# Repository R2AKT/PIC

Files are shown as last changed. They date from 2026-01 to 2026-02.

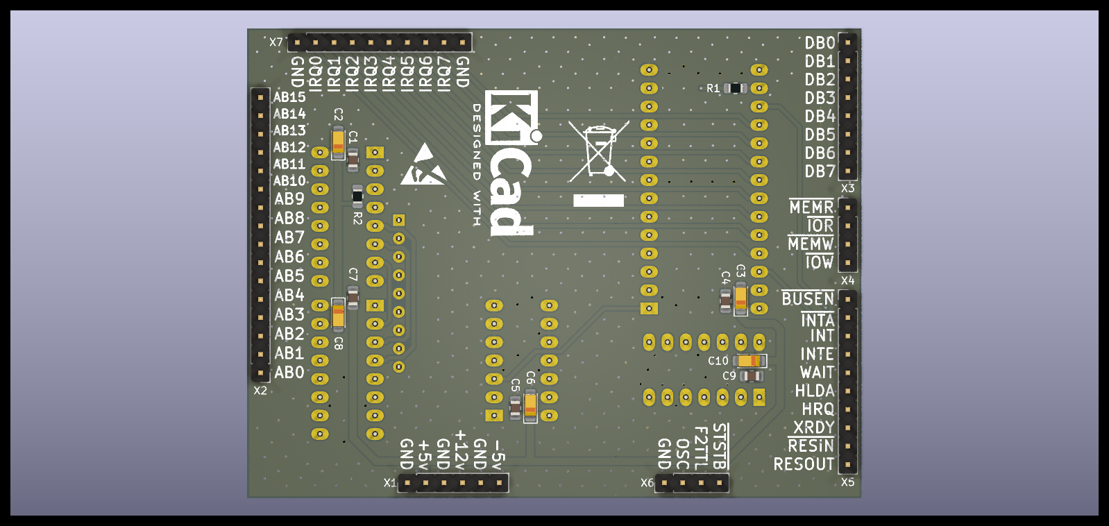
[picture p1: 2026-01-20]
PIC_btn.png

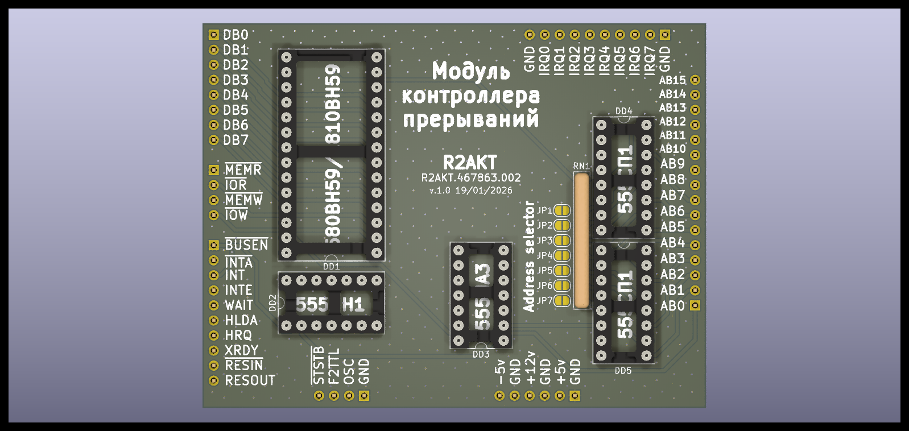
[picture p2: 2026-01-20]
PIC_top.png

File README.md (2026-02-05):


License addendum - https://github.com/R2AKT/PIC/blob/main/Addendum.txt
# PIC
Programmable Interrupt Contoller (PIC) module. For connection to the CPU_8080 processor board - https://github.com/R2AKT/CPU_8080.

Status: in production for testing

Модуль программируемого контроллера прерываний (PIC). Для подключения к процессорной плате CPU_8080 - https://github.com/R2AKT/CPU_8080.

На базе часов реального времени для РАДИО-86РК.

Статус: в изготовлении для тестирования.

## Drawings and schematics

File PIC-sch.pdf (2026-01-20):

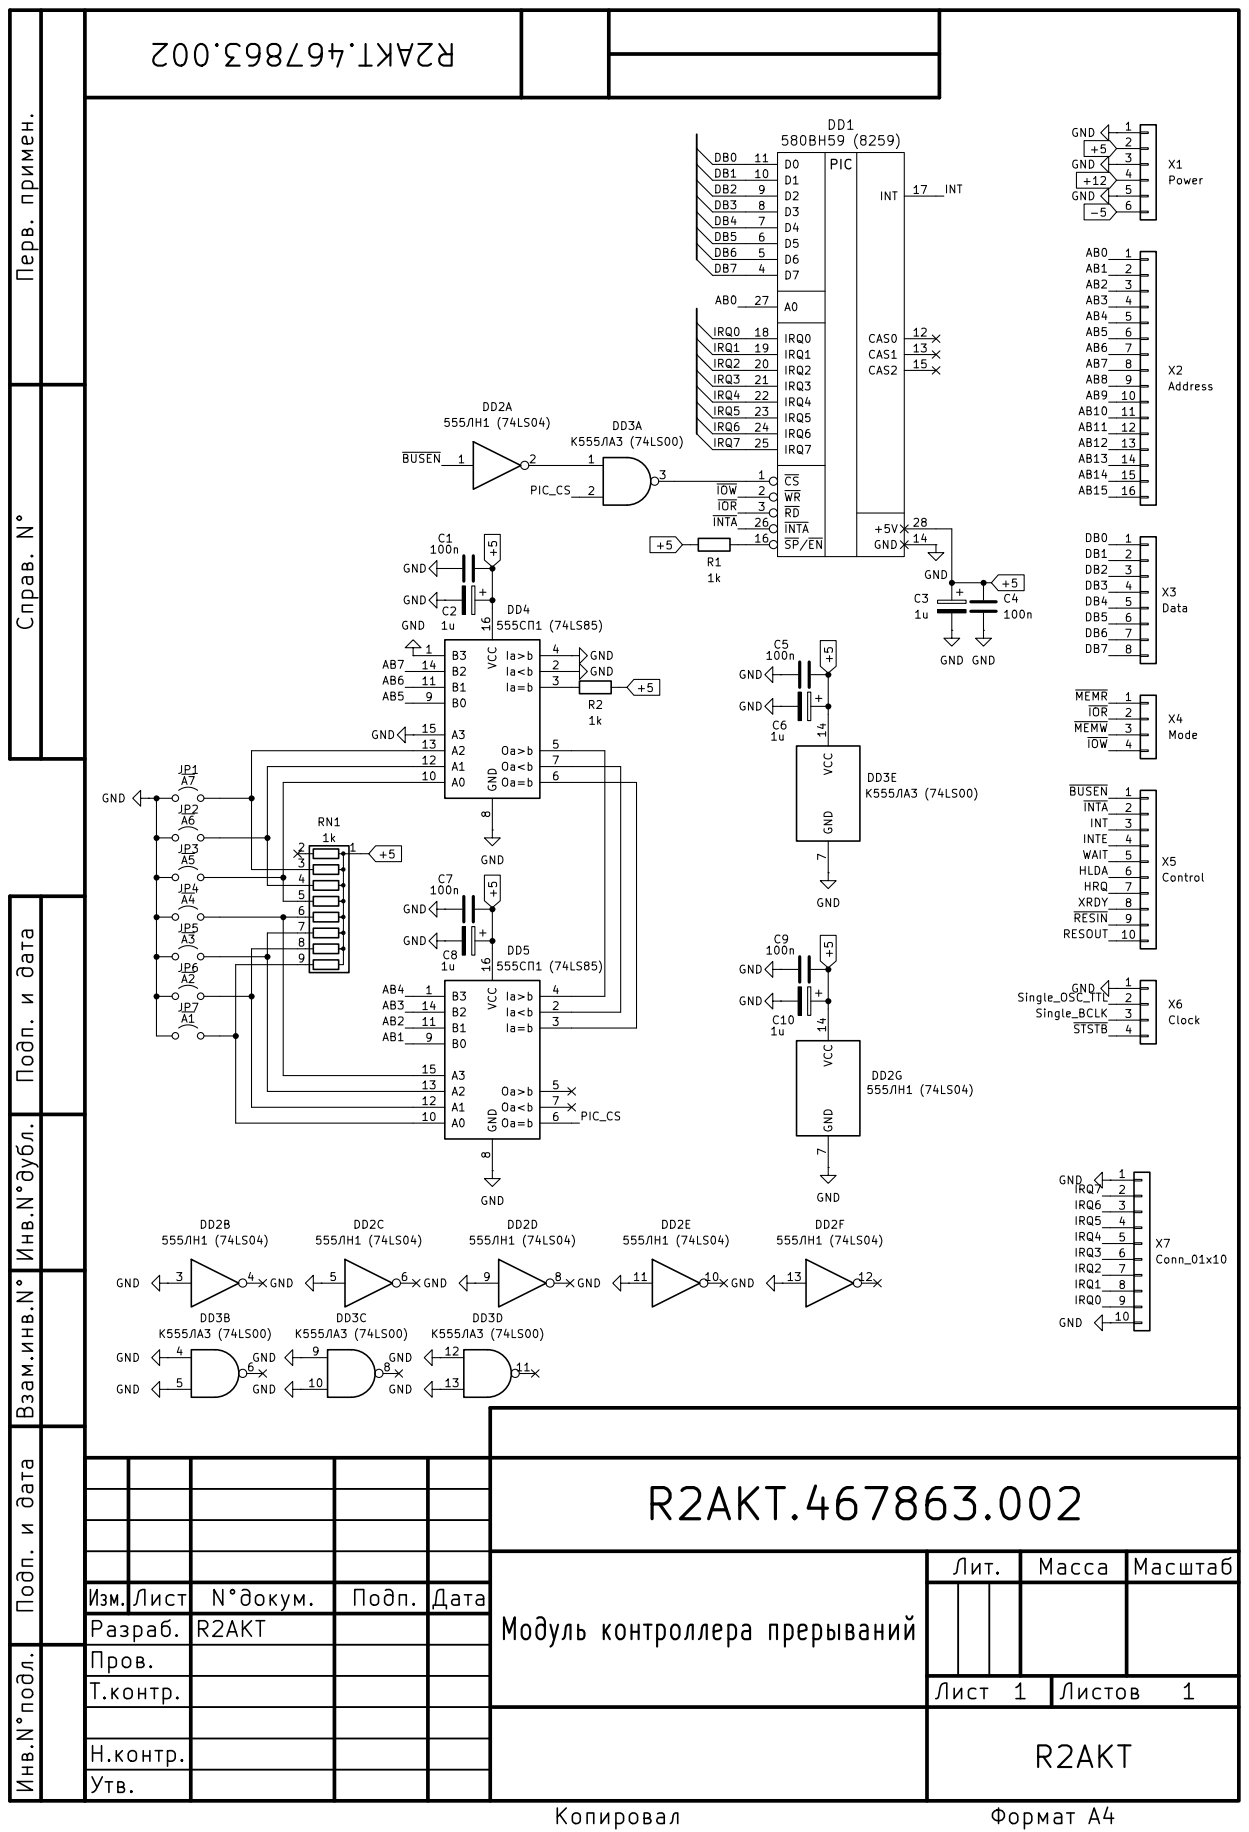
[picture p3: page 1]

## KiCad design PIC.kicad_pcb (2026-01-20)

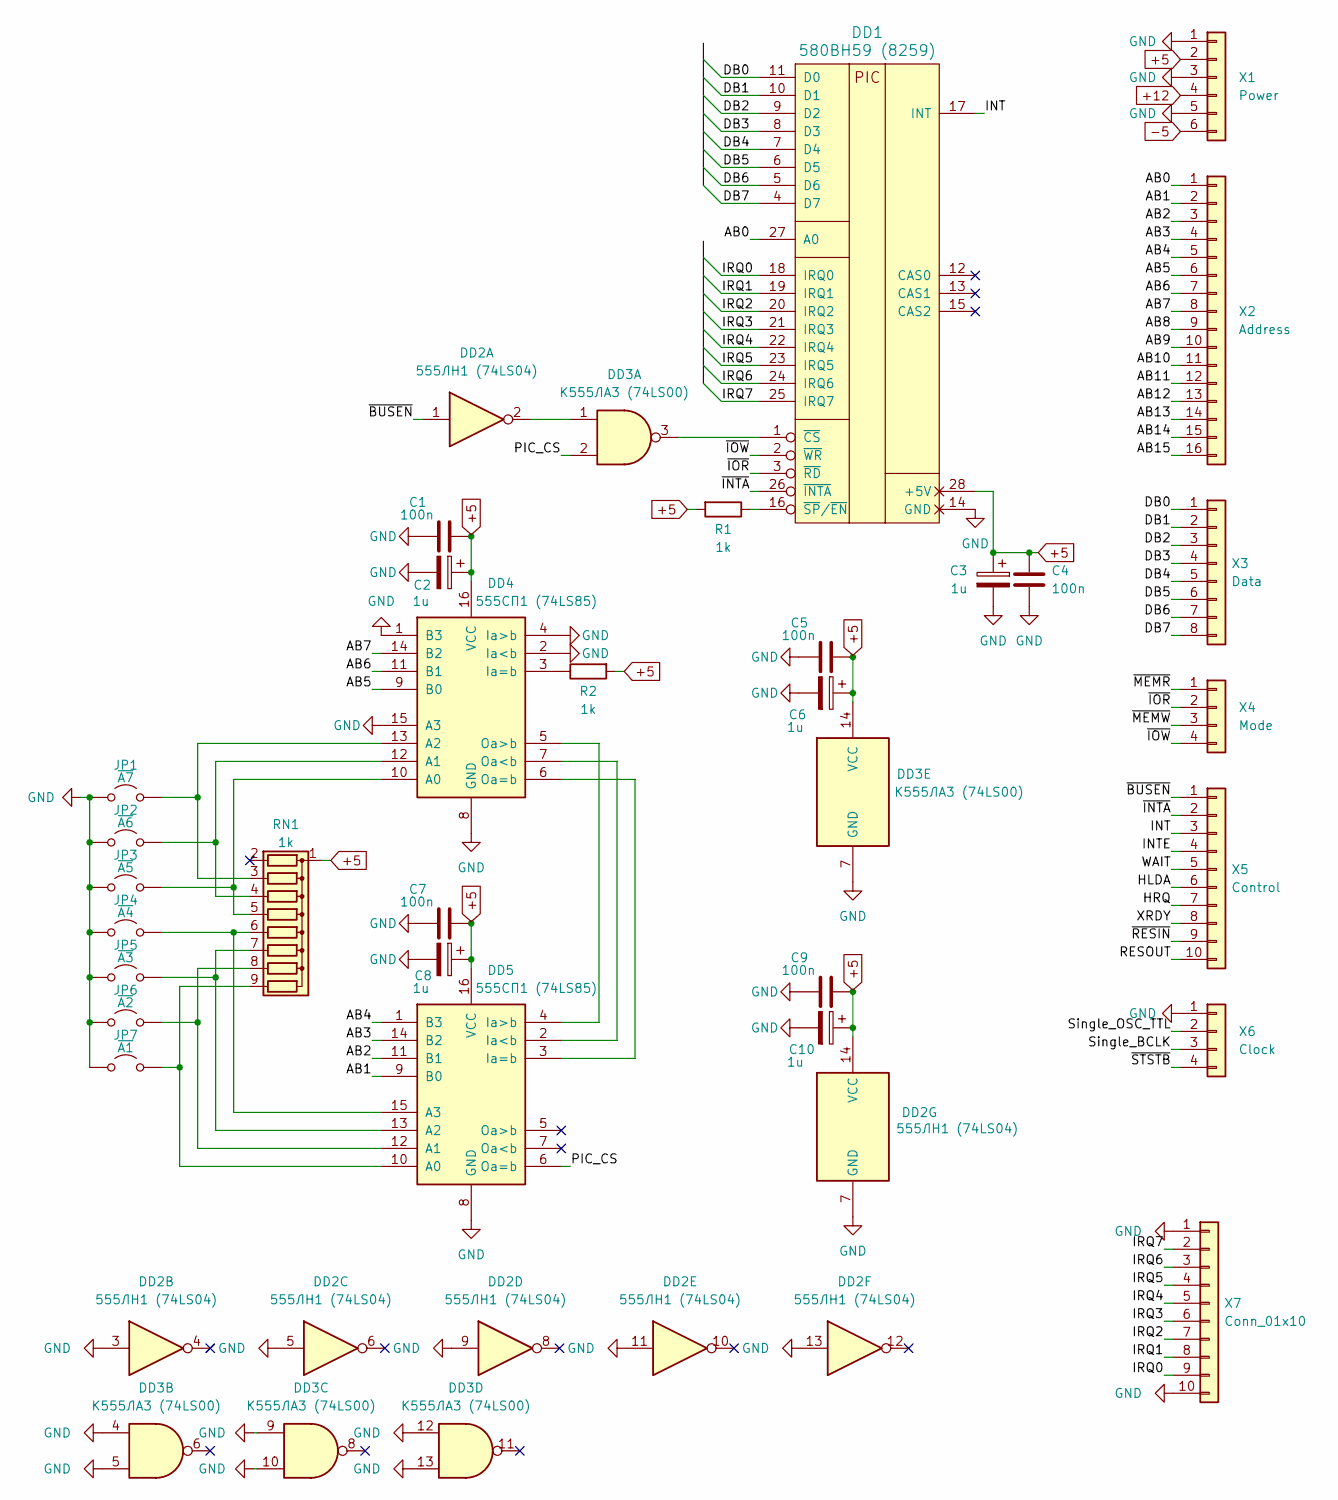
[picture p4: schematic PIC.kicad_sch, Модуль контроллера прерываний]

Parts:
C1, C4, C5, C7, C9: 100n; C_0805_2012Metric_Pad1.18x1.45mm_HandSolder
C2, C3, C6, C8, C10: 1u; CP_EIA-3216-18_Kemet-A_Pad1.58x1.35mm_HandSolder
DD1: 580ВН59 (8259); DIP-28_W15.24mm_Socket_LongPads
DD2: 555ЛН1 (74LS04); DIP-14_W7.62mm_Socket_LongPads
DD3: К555ЛА3 (74LS00); DIP-14_W7.62mm_Socket_LongPads
DD4, DD5: 555СП1 (74LS85); DIP-16_W7.62mm_Socket_LongPads
JP1: ~{A7}; SolderJumper-2_P1.3mm_Open_RoundedPad1.0x1.5mm
JP2: ~{A6}; SolderJumper-2_P1.3mm_Open_RoundedPad1.0x1.5mm
JP3: ~{A5}; SolderJumper-2_P1.3mm_Open_RoundedPad1.0x1.5mm
JP4: ~{A4}; SolderJumper-2_P1.3mm_Open_RoundedPad1.0x1.5mm
JP5: ~{A3}; SolderJumper-2_P1.3mm_Open_RoundedPad1.0x1.5mm
JP6: ~{A2}; SolderJumper-2_P1.3mm_Open_RoundedPad1.0x1.5mm
JP7: ~{A1}; SolderJumper-2_P1.3mm_Open_RoundedPad1.0x1.5mm
R1, R2: 1k; R_0805_2012Metric_Pad1.20x1.40mm_HandSolder
RN1: 1k; R_Array_SIP9
X1: Power; PinHeader_1x06_P2.54mm_Vertical
X2: Address; PinHeader_1x16_P2.54mm_Vertical
X3: Data; PinHeader_1x08_P2.54mm_Vertical
X4: Mode; PinHeader_1x04_P2.54mm_Vertical
X5: Control; PinHeader_1x10_P2.54mm_Vertical
X6: Clock; PinHeader_1x04_P2.54mm_Vertical
X7: Conn_01x10; PinHeader_1x10_P2.54mm_Vertical

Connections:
+5: C1.1, C2.1, C3.1, C4.1, C5.1, C6.1, C7.1, C8.1, C9.1, C10.1, DD1.28 (+5V), DD2.14 (VCC), DD3.14 (VCC), DD4.16 (VCC), DD5.16 (VCC), R1.2, R2.2, RN1.1 (common), X1.2
+12: X1.4
-5: X1.6
/AB0: DD1.27 (A0), X2.1
/AB1: DD5.9 (B0), X2.2
/AB2: DD5.11 (B1), X2.3
/AB3: DD5.14 (B2), X2.4
/AB4: DD5.1 (B3), X2.5
/AB5: DD4.9 (B0), X2.6
/AB6: DD4.11 (B1), X2.7
/AB7: DD4.14 (B2), X2.8
/AB8: X2.9
/AB9: X2.10
/AB10: X2.11
/AB11: X2.12
/AB12: X2.13
/AB13: X2.14
/AB14: X2.15
/AB15: X2.16
/DB0: DD1.11 (D0), X3.1
/DB1: DD1.10 (D1), X3.2
/DB2: DD1.9 (D2), X3.3
/DB3: DD1.8 (D3), X3.4
/DB4: DD1.7 (D4), X3.5
/DB5: DD1.6 (D5), X3.6
/DB6: DD1.5 (D6), X3.7
/DB7: DD1.4 (D7), X3.8
/HLDA: X5.6
/HRQ: X5.7
/INT: DD1.17 (INT), X5.3
/INTE: X5.4
/IRQ0: DD1.18 (IRQ0), X7.9
/IRQ1: DD1.19 (IRQ1), X7.8
/IRQ2: DD1.20 (IRQ2), X7.7
/IRQ3: DD1.21 (IRQ3), X7.6
/IRQ4: DD1.22 (IRQ4), X7.5
/IRQ5: DD1.23 (IRQ5), X7.4
/IRQ6: DD1.24 (IRQ6), X7.3
/IRQ7: DD1.25 (IRQ7), X7.2
/PIC_CS: DD3.2, DD5.6 (Oa=b)
/RESOUT: X5.10
/Single_BCLK: X6.3
/Single_OSC_TTL: X6.2
/WAIT: X5.5
/XRDY: X5.8
/~BUSEN: DD2.1, X5.1
/~INTA: DD1.26 (~INTA), X5.2
/~IOR: DD1.3 (~RD), X4.2
/~IOW: DD1.2 (~WR), X4.4
/~MEMR: X4.1
/~MEMW: X4.3
/~RESIN: X5.9
/~STSTB: X6.4
GND: C1.2, C2.2, C3.2, C4.2, C5.2, C6.2, C7.2, C8.2, C9.2, C10.2, DD1.14 (GND), DD2.3, DD2.5, DD2.7 (GND), DD2.9, DD2.11, DD2.13, DD3.4, DD3.5, DD3.7 (GND), DD3.9, DD3.10, DD3.12, DD3.13, DD4.1 (B3), DD4.2 (Ia<b), DD4.4 (Ia>b), DD4.8 (GND), DD4.15 (A3), DD5.8 (GND), JP1.1 (A), JP2.1 (A), JP3.1 (A), JP4.1 (A), JP5.1 (A), JP6.1 (A), JP7.1 (A), X1.1, X1.3, X1.5, X6.1, X7.1, X7.10
unnamed: DD1.1 (~CS), DD3.3
unnamed: DD1.16 (~SP/~EN), R1.1
unnamed: DD2.2, DD3.1
unnamed: DD4.10 (A0), JP3.2 (B), RN1.5 (R4)
unnamed: DD4.12 (A1), JP2.2 (B), RN1.4 (R3)
unnamed: DD4.13 (A2), JP1.2 (B), RN1.3 (R2)
unnamed: DD4.3 (Ia=b), R2.1
unnamed: DD4.7 (Oa<b), DD5.2 (Ia<b)
unnamed: DD4.6 (Oa=b), DD5.3 (Ia=b)
unnamed: DD4.5 (Oa>b), DD5.4 (Ia>b)
unnamed: DD5.10 (A0), JP7.2 (B), RN1.9 (R8)
unnamed: DD5.12 (A1), JP6.2 (B), RN1.8 (R7)
unnamed: DD5.13 (A2), JP5.2 (B), RN1.7 (R6)
unnamed: DD5.15 (A3), JP4.2 (B), RN1.6 (R5)

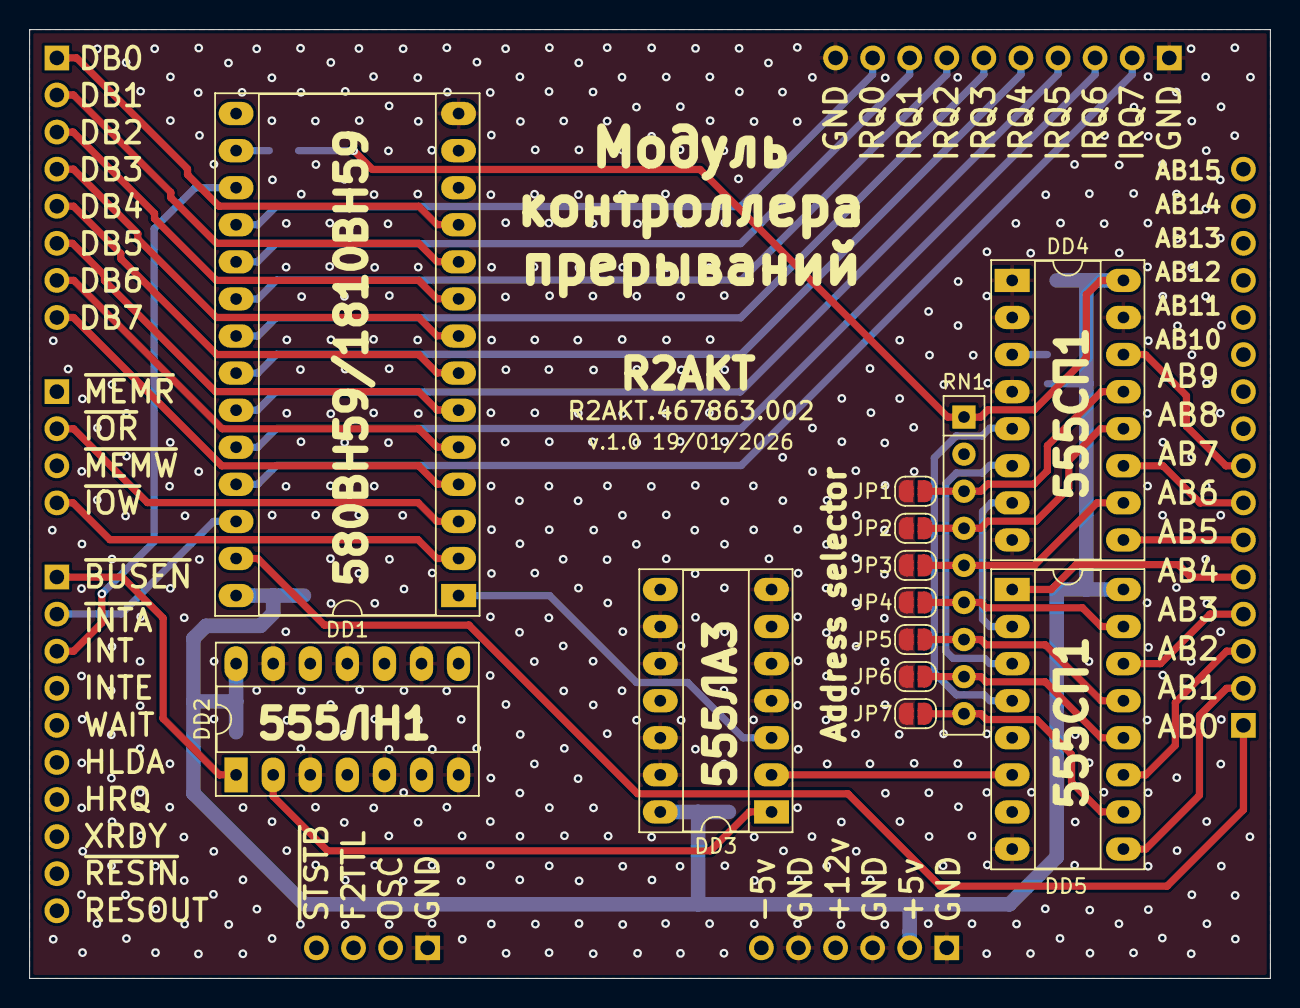
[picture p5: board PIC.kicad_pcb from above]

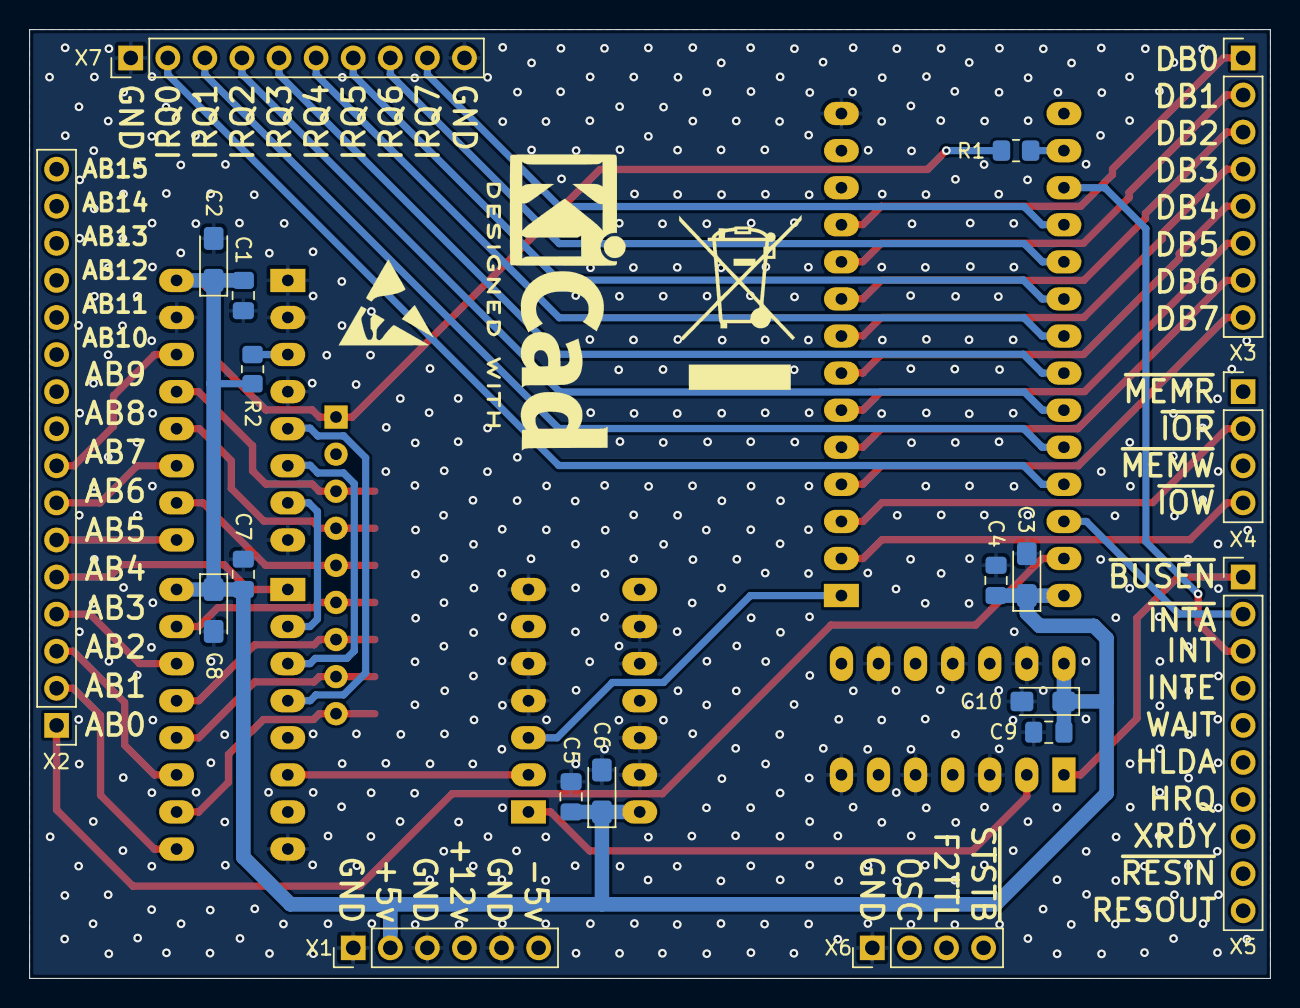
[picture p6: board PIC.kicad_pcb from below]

Board: 2 copper layers, 85.0 x 65.0 mm, 32 parts (19 on the bottom side), 46 nets.

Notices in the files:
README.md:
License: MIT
